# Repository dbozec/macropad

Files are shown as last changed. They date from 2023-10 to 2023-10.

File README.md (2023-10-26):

# Macropad

This is a custom macropad with 4x4 keys and a rotary knob.

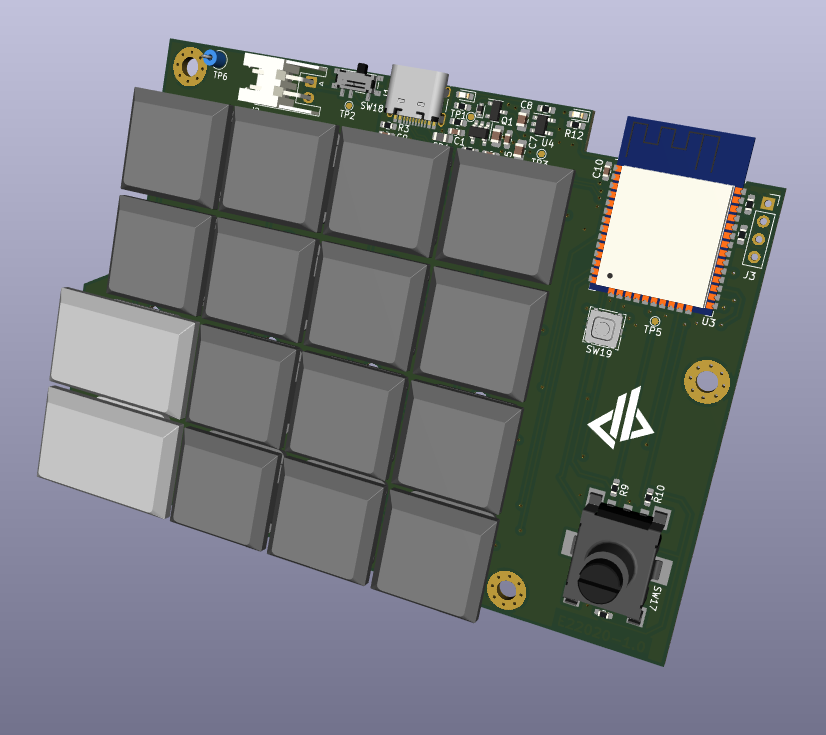
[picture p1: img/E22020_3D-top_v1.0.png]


I wanted it to be wireless so it is built arround an ESP32 module with Bluetooth.

It is built to be used with Kailh Choc keyswitches to have a lower profile than classical mechanical switches.

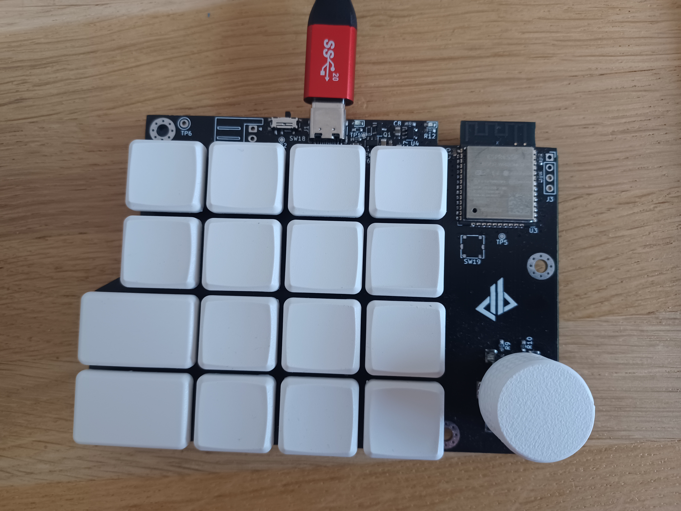
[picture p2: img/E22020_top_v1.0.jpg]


Shortly after I started to work on this project, the folks from [DeepSea-Developments](https://github.com/DeepSea-Developments) announced their own work on the [DeepDeck](https://deepdeck.co/) macropad. So I benefit from their work to design my own macropad.

I also switched from other existing firmwares I was trying to their work on the [DeepDeck firmware](https://github.com/DeepSea-Developments/DeepDeck.Ahuyama.fw)

## Warnings
My work is distributed in the home it can be useful, but **WITHOUT ANY WARRANTY**

This product is meant to be used with battery, but v1.0 has never be tested in battery power mode right now, so take care of what you do.

## Thanks
- To [DeepSea-Developments](https://www.deepseadev.com/), creators of the [DeepDeck](https://deepdeck.co/) macropad for their work.
- To [Yannick Hemery](https://github.com/yhemery), for taking time to fine tune the DeepDeck firmware to fit my hardware design.

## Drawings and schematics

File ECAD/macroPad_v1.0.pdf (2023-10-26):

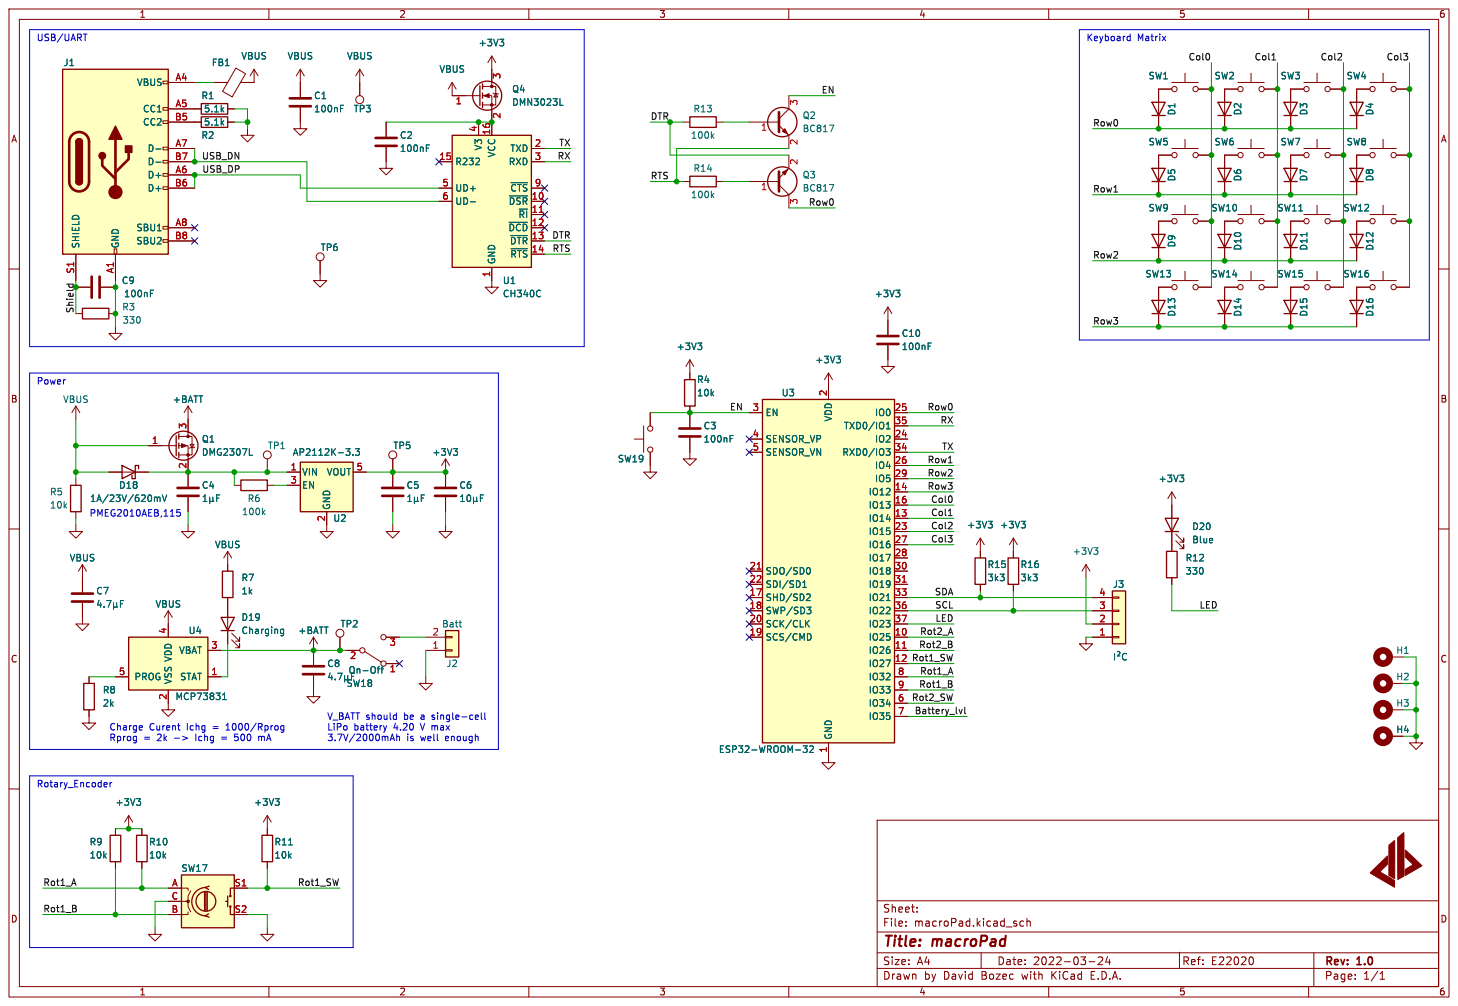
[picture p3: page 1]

4 UD+ 5 UD- 6 ~{CTS}9 VBUS

1 ~{DSR} 10 ~{RI} 11 ~{DCD} 12 ~{DTR} 13 ~{RTS} 14 R232 15 VCC 16 TXD 2 RXD 3 V3

2 SCK/CLK 20 SDO/SD0 21 SDI/SD1 22

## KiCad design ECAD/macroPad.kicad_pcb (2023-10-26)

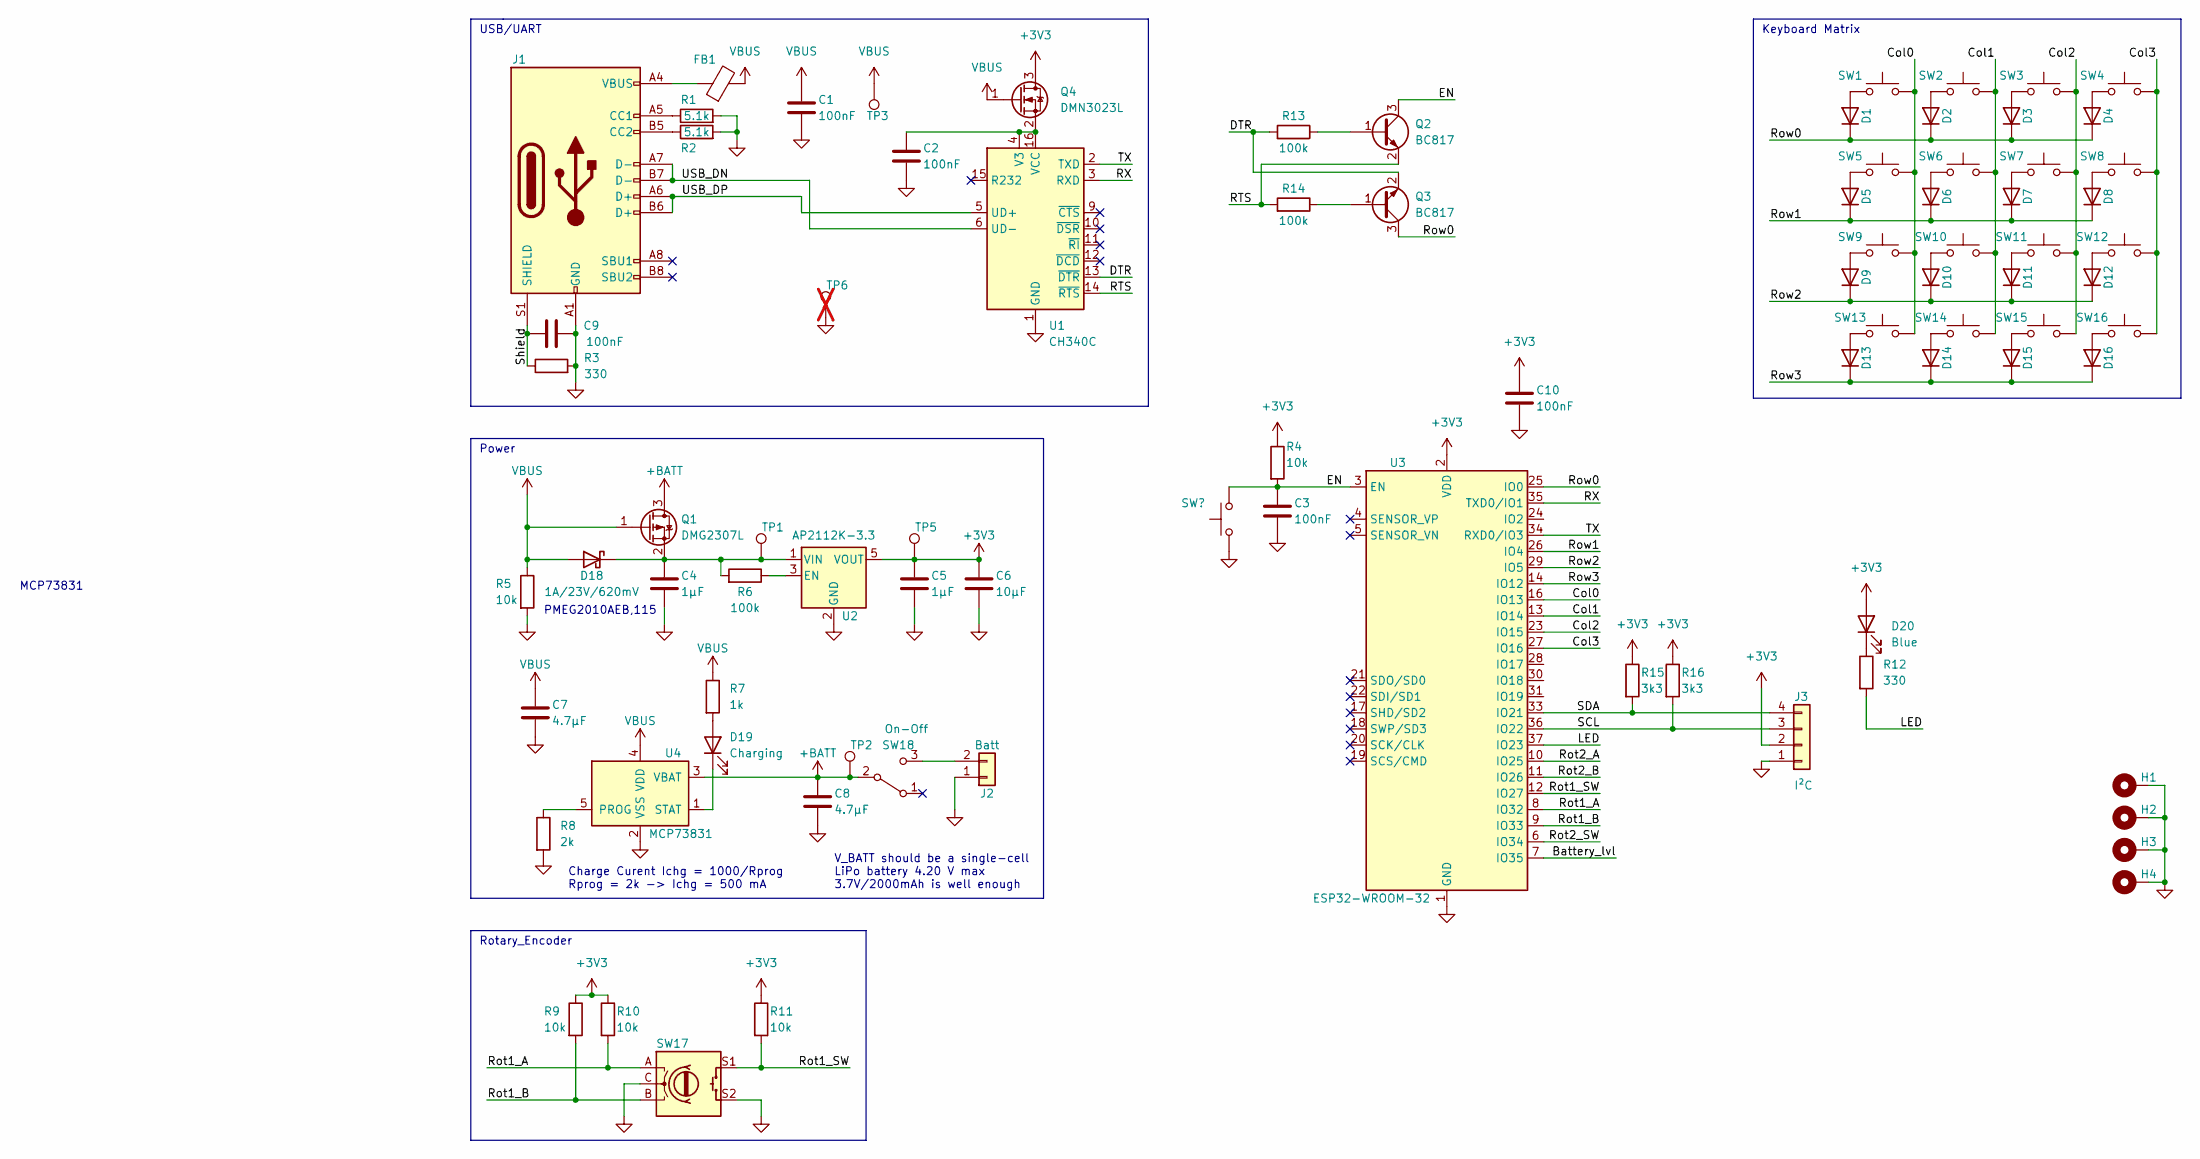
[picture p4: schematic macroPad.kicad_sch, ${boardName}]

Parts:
C1, C2, C3, C9, C10: 100nF; C_0603_1608Metric_Pad1.08x0.95mm_HandSolder
C4, C5: 1µF; C_0603_1608Metric_Pad1.08x0.95mm_HandSolder
C6: 10µF; C_0805_2012Metric_Pad1.18x1.45mm_HandSolder
C7, C8: 4.7µF; C_0805_2012Metric_Pad1.18x1.45mm_HandSolder
D1, D2, D3, D4, D5, D6, D7, D8, D9, D10, D11, D12, D13, D14, D15, D16: MMSD4148; D_SOD-123
D18: 1A/23V/620mV; D_SOD-523
D19: Charging; LED_0603_1608Metric_Pad1.05x0.95mm_HandSolder
D20: Blue; LED_0603_1608Metric_Pad1.05x0.95mm_HandSolder
FB1: FerriteBead; L_0805_2012Metric_Pad1.05x1.20mm_HandSolder
H1, H2, H3, H4: MountingHole_Pad; MountingHole_3.2mm_M3_Pad_Via
J1: USB_C_Receptacle_USB2.0; USB_C_Receptacle_HRO_TYPE-C-31-M-12
J2: Batt; JST_EH_S2B-EH_1x02_P2.50mm_Horizontal
J3: I²C; PinSocket_1x04_P2.54mm_Vertical
Q1: DMG2307L; SOT-23
Q2, Q3: BC817; SOT-23
Q4: DMN3023L
R1, R2: 5.1k; R_0603_1608Metric_Pad0.98x0.95mm_HandSolder
R3, R12: 330; R_0603_1608Metric_Pad0.98x0.95mm_HandSolder
R4, R5, R9, R10, R11: 10k; R_0603_1608Metric_Pad0.98x0.95mm_HandSolder
R6, R13, R14: 100k; R_0603_1608Metric_Pad0.98x0.95mm_HandSolder
R7: 1k; R_0603_1608Metric_Pad0.98x0.95mm_HandSolder
R8: 2k; R_0603_1608Metric_Pad0.98x0.95mm_HandSolder
R15, R16: 3k3; R_0603_1608Metric_Pad0.98x0.95mm_HandSolder
SW1, SW2, SW3, SW4, SW5, SW6, SW7, SW8, SW9, SW10, SW11, SW12, SW13, SW14, SW15, SW16: Keyswitch; PG1350_optional-socket
SW17: RotaryEncoder_Switch; RotaryEncoder_Bourns_PEC11S-929K-Switch_Vertical
SW18: On-Off; SW_Slide_Mini_Wurth_450404015514
TP1: Vin; TestPoint_Pad_D1.0mm
TP2: VBAT; TestPoint_Pad_D1.0mm
TP3: VBUS; TestPoint_Pad_D1.0mm
TP5: +3V3; TestPoint_Pad_D1.0mm
TP6: GND; TestPoint_Loop_D1.80mm_Drill1.0mm_Beaded; not fitted
U1: CH340C; SOIC-16_3.9x9.9mm_P1.27mm
U2: AP2112K-3.3; SOT-23-5
U3: ESP32-WROOM-32
U4: MCP73831; SOT-23-5

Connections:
+3V3: C5.1, C6.1, C10.1, D20.2 (A), J3.2, Q4.3 (D), R4.1, R9.1, R10.1, R11.1, R15.1, R16.1, TP5.1, U2.5 (VOUT), U3.2 (VDD)
+BATT: C8.1, Q1.3 (D), SW18.2 (B), TP2.1, U4.3 (VBAT)
/Battery_lvl: U3.7 (IO35)
/Col1: SW2.2, SW6.2, SW10.2, SW14.2, U3.13 (IO14)
/Col2: SW3.2, SW7.2, SW11.2, SW15.2, U3.23 (IO15)
/Col3: SW4.2, SW8.2, SW12.2, SW16.2, U3.27 (IO16)
/DTR: Q3.2 (E), R13.2, U1.13 (~DTR)
/LED: R12.2, U3.37 (IO23)
/RTS: Q2.2 (E), R14.2, U1.14 (~RTS)
/RX: U1.3 (RXD), U3.35 (TXD0/IO1)
/Rot1_A: R10.2, SW17.A, U3.8 (IO32)
/Rot1_B: R9.2, SW17.B, U3.9 (IO33)
/Rot1_SW: R11.2, SW17.S1, U3.12 (IO27)
/Rot2_A: U3.10 (IO25)
/Rot2_B: U3.11 (IO26)
/Rot2_SW: U3.6 (IO34)
/Row0: D1.1 (K), D2.1 (K), D3.1 (K), D4.1 (K), Q3.3 (C), U3.25 (IO0)
/Row1: D5.1 (K), D6.1 (K), D7.1 (K), D8.1 (K), U3.26 (IO4)
/Row2: D9.1 (K), D10.1 (K), D11.1 (K), D12.1 (K), U3.29 (IO5)
/Row3: D13.1 (K), D14.1 (K), D15.1 (K), D16.1 (K), U3.14 (IO12)
/SCL: J3.3, R16.2, U3.36 (IO22)
/SDA: J3.4, R15.2, U3.33 (IO21)
/Shield: C9.1, J1.S1 (SHIELD), R3.1; also elsewhere on the board
/TX: U1.2 (TXD), U3.34 (RXD0/IO3)
/USB_DN: J1.A7 (D-), J1.B7 (D-), U1.6 (UD-); also elsewhere on the board
/USB_DP: J1.A6 (D+), J1.B6 (D+), U1.5 (UD+); also elsewhere on the board
unnamed: C2.1, Q4.2 (S), U1.4 (V3), U1.16 (VCC)
unnamed: C4.1, D18.1 (K), Q1.2 (S), R6.2, TP1.1, U2.1 (VIN)
unnamed: D2.2 (A), SW2.1
unnamed: D3.2 (A), SW3.1
unnamed: D4.2 (A), SW4.1
unnamed: D5.2 (A), SW5.1
unnamed: D6.2 (A), SW6.1
unnamed: D7.2 (A), SW7.1
unnamed: D8.2 (A), SW8.1
unnamed: D9.2 (A), SW9.1
unnamed: D10.2 (A), SW10.1
unnamed: D11.2 (A), SW11.1
unnamed: D12.2 (A), SW12.1
unnamed: D13.2 (A), SW13.1
unnamed: D14.2 (A), SW14.1
unnamed: D15.2 (A), SW15.1
unnamed: D16.2 (A), SW16.1
unnamed: D19.1 (K), U4.1 (STAT)
unnamed: D19.2 (A), R7.2
unnamed: D20.1 (K), R12.1
unnamed 46: FB1.1, J1.A4 (VBUS), J1.A9 (VBUS), J1.B4 (VBUS), J1.B9 (VBUS); also elsewhere on the board
unnamed 47: J1.A5 (CC1), R1.1; also elsewhere on the board
unnamed 48: J1.B5 (CC2), R2.1; also elsewhere on the board
unnamed: Q2.1 (B), R13.1
unnamed: Q3.1 (B), R14.1
unnamed: R6.1, U2.3 (EN)
unnamed: R8.1, U4.5 (PROG)
unnamed: J2.2, SW18.3 (C)
VBUS: C1.1, C7.1, D18.2 (A), FB1.2, Q1.1 (G), Q4.1 (G), R5.1, R7.1, TP3.1, U4.4 (VDD)

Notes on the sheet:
USB/UART
Power
MCP73831
V_BATT should be a single-cell LiPo battery 4.20 V max 3.7V/2000mAh is well enough
PMEG2010AEB,115
Rotary_Encoder
Keyboard Matrix
Charge Curent Ichg = 1000/Rprog Rprog = 2k -> Ichg = 500 mA

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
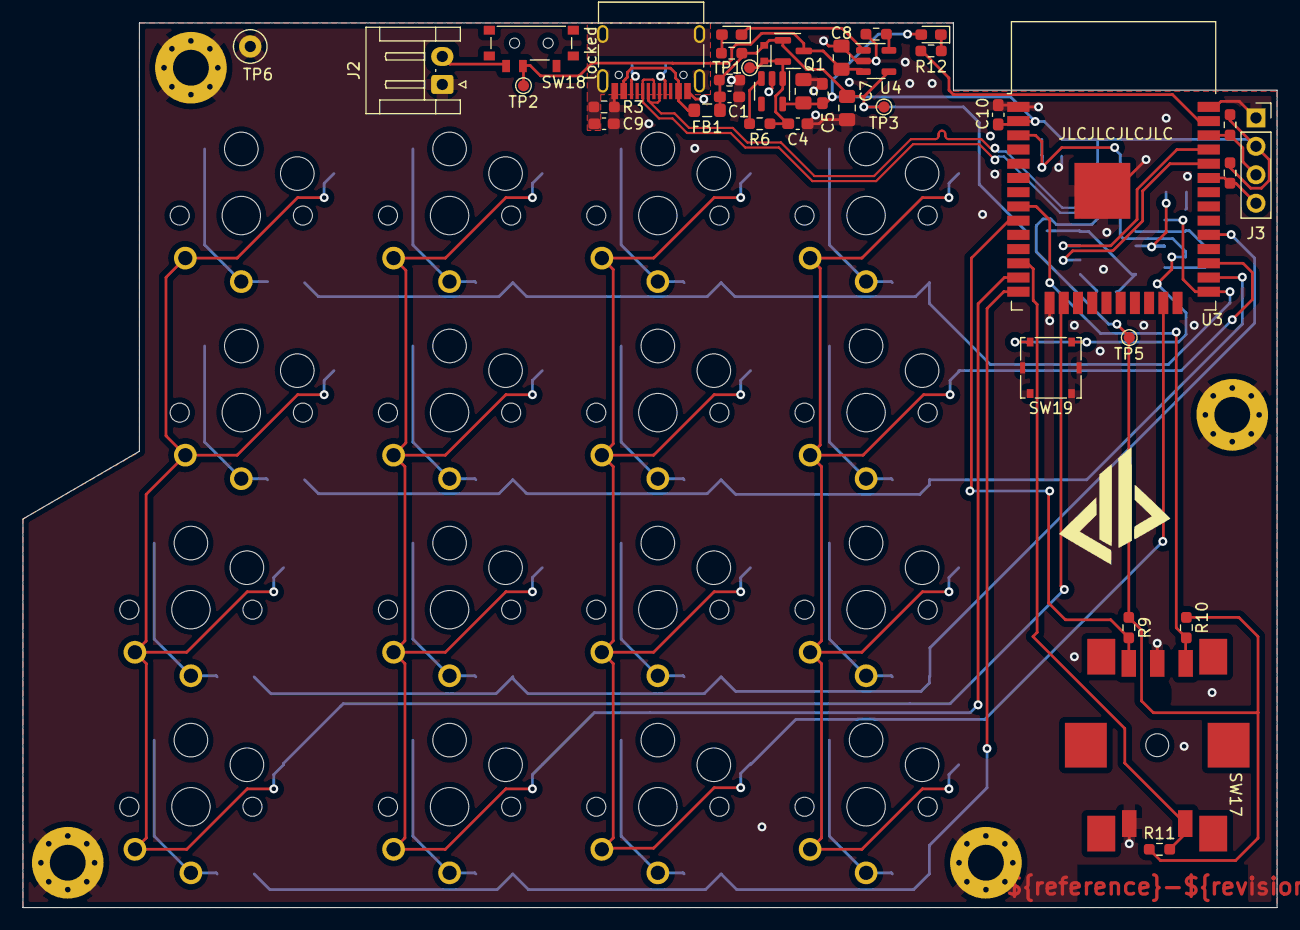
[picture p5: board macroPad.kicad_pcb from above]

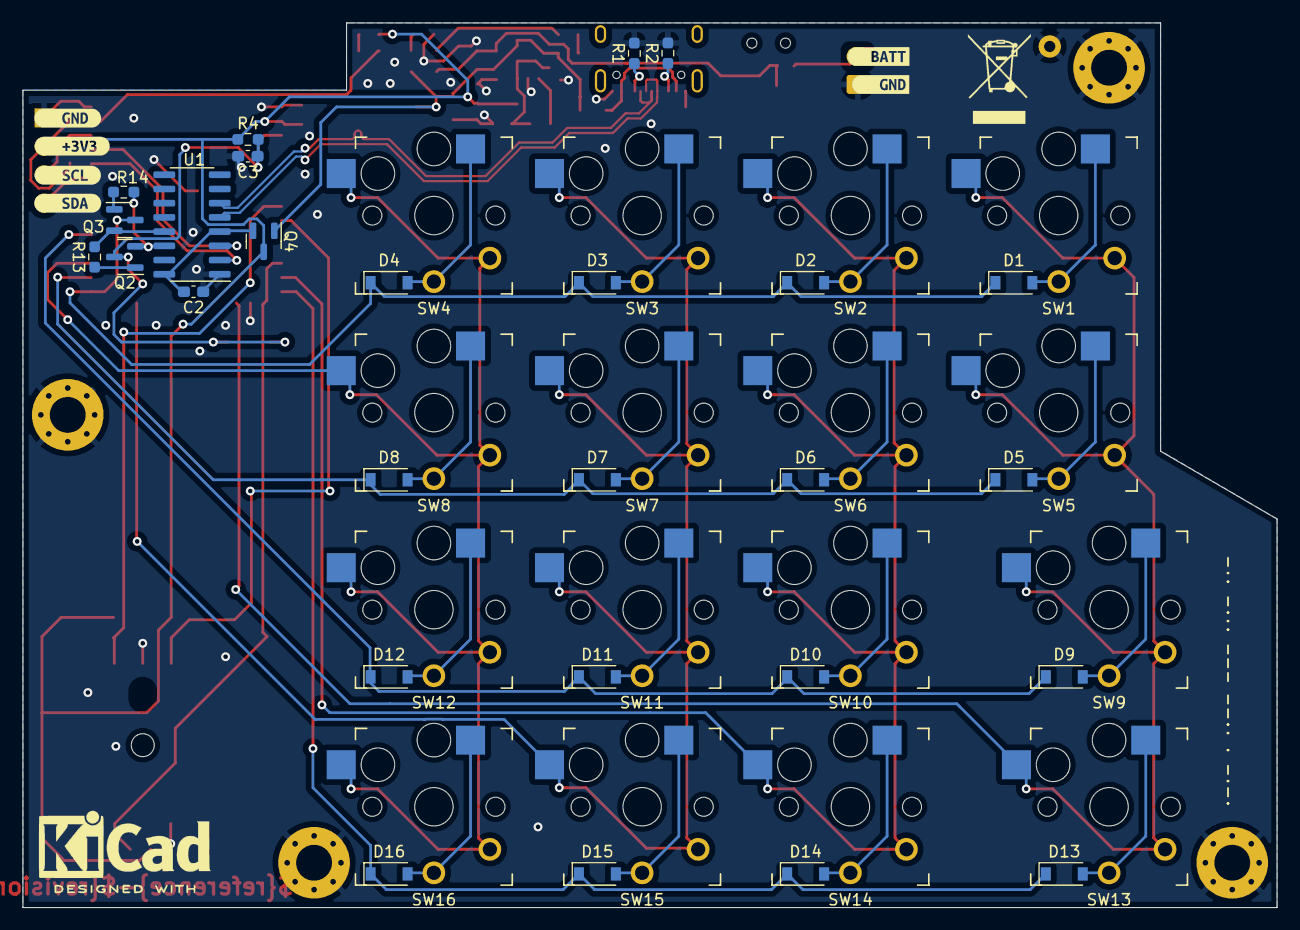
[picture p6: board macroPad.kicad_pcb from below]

Board: 2 copper layers, 112.0 x 79.0 mm, 91 parts (33 on the bottom side), 55 nets.

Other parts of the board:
SW19: Reset; SW_Tact_5x5mm_Wurth_431183015816
kibuzzard-63541E8A: G***; kibuzzard-63541E8A
kibuzzard-635127E0: G***; kibuzzard-635127E0
kibuzzard-6351268B: G***; kibuzzard-6351268B
kibuzzard-63512619: G***; kibuzzard-63512619
kibuzzard-63512654: G***; kibuzzard-63512654
kibuzzard-63512665: G***; kibuzzard-63512665
locked: USB_C_Receptacle_USB2.0; USB_C_Receptacle_HRO_TYPE-C-31-M-12

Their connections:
/Shield: locked.S1 (SHIELD); also elsewhere on the board
/USB_DN: locked.A7 (D-), locked.B7 (D-); also elsewhere on the board
/USB_DP: locked.A6 (D+), locked.B6 (D+); also elsewhere on the board
unnamed 46: locked.A4 (VBUS), locked.A9 (VBUS), locked.B4 (VBUS), locked.B9 (VBUS); also elsewhere on the board
unnamed 47: locked.A5 (CC1); also elsewhere on the board
unnamed 48: locked.B5 (CC2); also elsewhere on the board

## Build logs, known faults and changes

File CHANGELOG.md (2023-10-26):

# Changelog

## [Unreleased](https://github.com/dbozec/macropad)

**Implemented enhancements:**
- add gitignore file

**Fixed bugs:**

## [v1.0](https://github.com/dbozec/macropad/releases/tag/v1.0) (2022-10-24)

**Implemented enhancements:**
- First Prototype
